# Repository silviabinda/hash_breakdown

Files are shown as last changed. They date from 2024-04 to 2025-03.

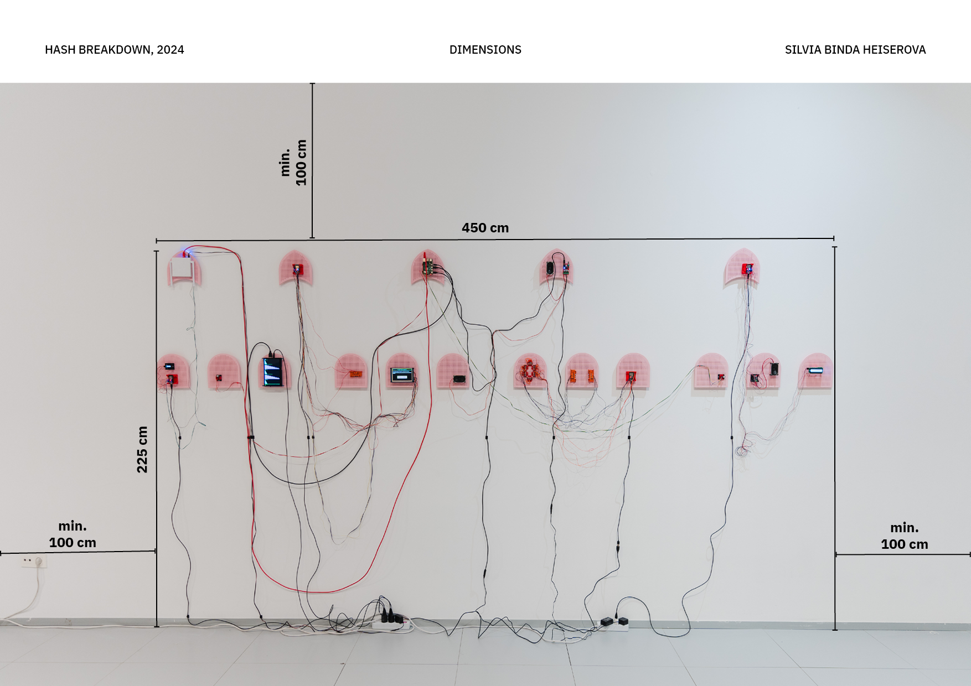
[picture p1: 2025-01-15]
schematics/dimensions.png

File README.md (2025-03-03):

# Hash Breakdown, 2024
SILVIA_BINDA_ETOPIA_JULIAN-FALLAS-28 copy
>Photo by: Julian Fallas

## About
The artwork “Hash Breakdown" is an autonomous system constituted by an electronic and digital ensamble of microcomputers, modules, 3D prints, sensors and codes with real-time functionality. This critical interface parses sentences related to the keywords “feminism is” from the world wide web and then starts a slowed-down explanatory process of converting the parsed sentence into a hash, using the SHA-256 algorithm. What normally takes less than a millisecond, is here extended into a 4-minute explanatory cycle, represented visually within a structure imitating a simplified logic gates diagram of the very same SHA-256 hashing function.

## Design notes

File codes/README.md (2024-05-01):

# ESP32 general information:

The esp32_1 to esp32_4 codes are run on an ESP32 WROOM 30PIN model with following PinOuts:

ESP32_Pinout

> Image source and more info: https://circuits4you.com/2018/12/31/esp32-devkit-esp32-wroom-gpio-pinout/

# Communication with Raspberry Pi4 model B
Each of the ESP32 receives UDP messages from the Raspberry Pi4 model B via Wifi using an offline router with IP adresses reserved for each of the ESP32.

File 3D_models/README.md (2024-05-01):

# Info on 3D models

In the folder "3D_models", you can find .stl files of all the 3D printed parts that are included in the Hash Breakdown artwork.

First, print the base modules from the folder "base". Altoghether, in the final set up, there are 17 basic modules, 5 of which represent the OR logic gate and 12 representing the AND logic gate.

In the "holders" folder, you will find different types of holders for components such as ESP32, amplifier, oled display.

Finally, in the "wall_mount" folder there is the piece that serves to mount the module on the wall, print 1 piece for each module, in this case that would be 17 piecies.  

# Details on 3D printed parts:

- 3D printer used: Sovol SV07 
- Rose filament: eSUN ePLA-Matte Peach Pink
- Red filament: eSUN PLA+ red
- Black filament: generic PLA matte

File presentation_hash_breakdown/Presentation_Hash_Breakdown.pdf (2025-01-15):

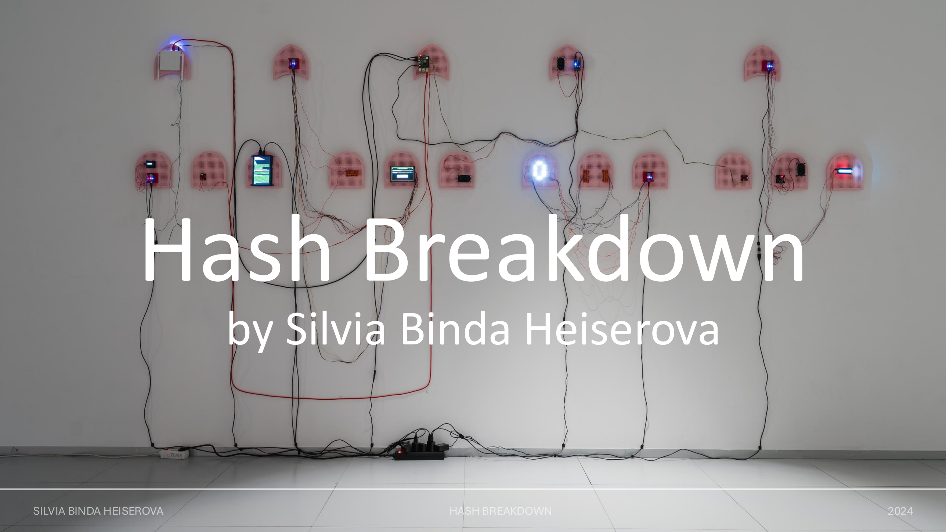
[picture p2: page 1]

# Hash Breakdown

### by Silvia Binda Heiserova

1

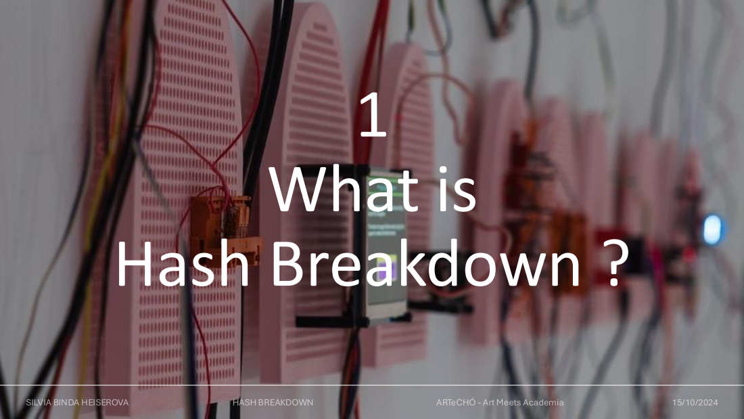
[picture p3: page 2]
What is Hash Breakdown ?

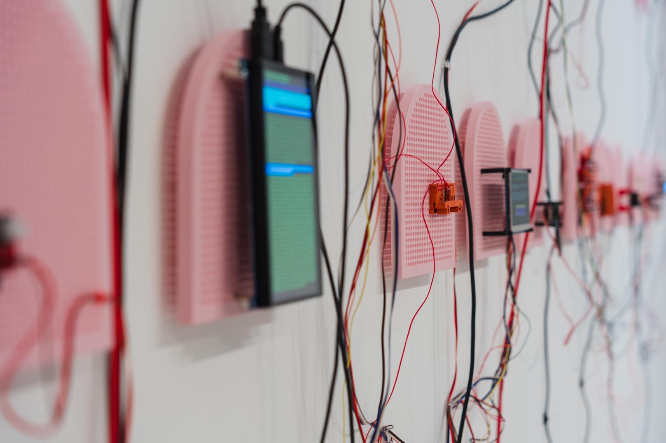
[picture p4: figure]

# Critical Interface

demystifying the
SHA-256 hashing
algorithm

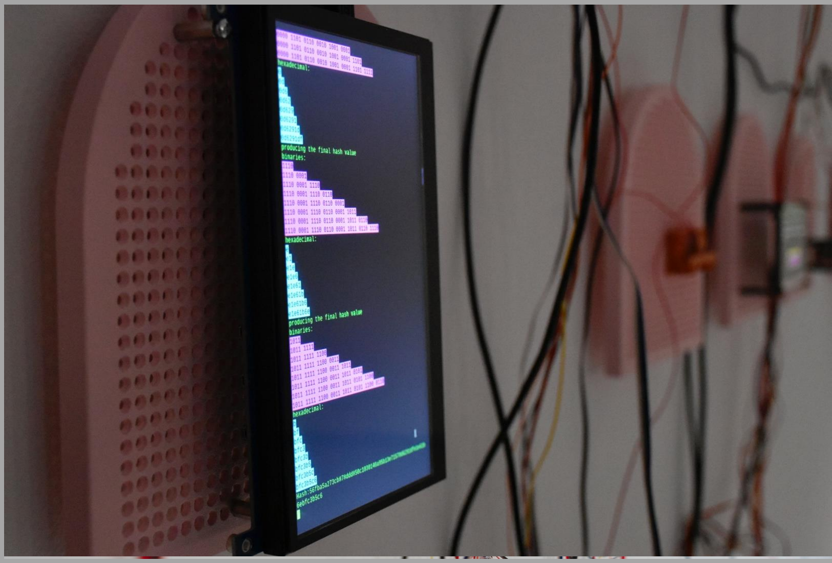
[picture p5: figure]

# Critique

towards mystifying,
elitist, masculine
narratives around
blockchain

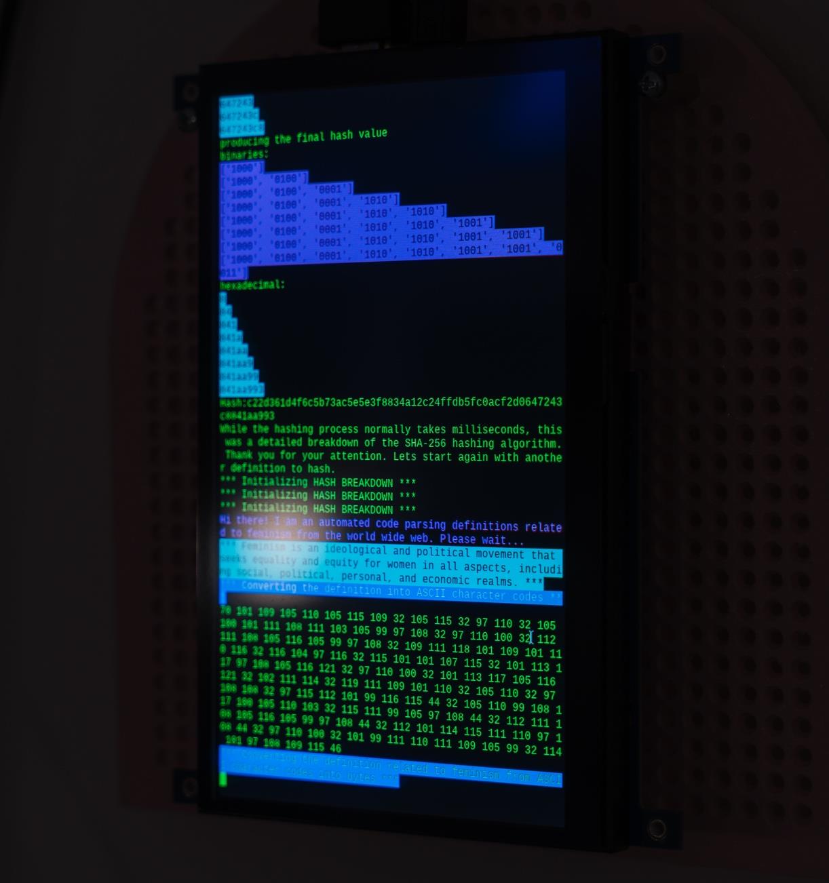
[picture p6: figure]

# Explanatory Process

slowed-down version
of the data conversion into a hash

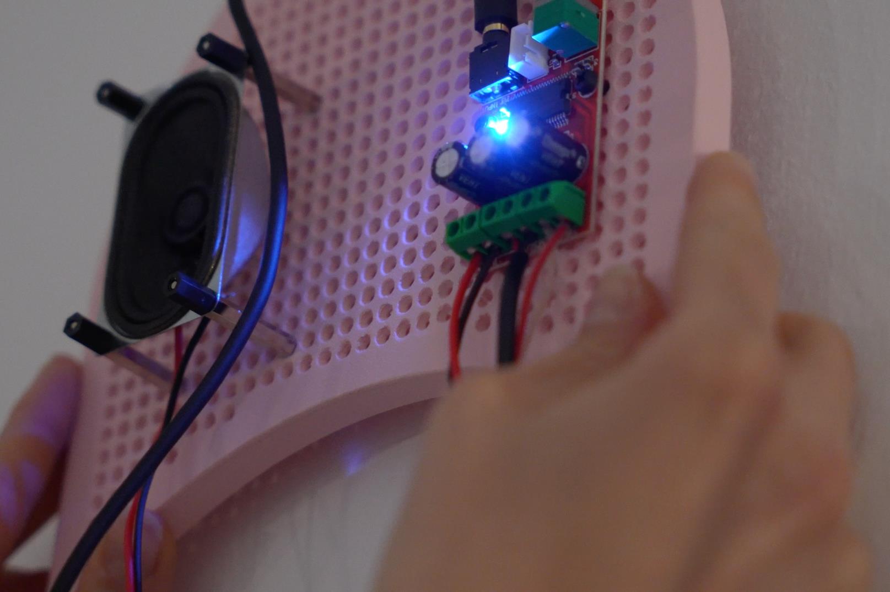
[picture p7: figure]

Material,
Visual,

# Sonic

representation of
SHA-256

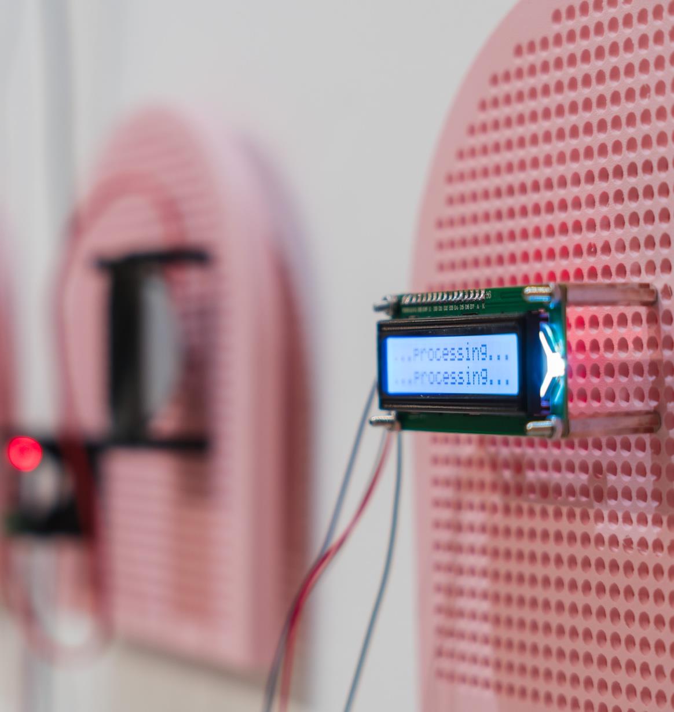
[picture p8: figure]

# Autonomous System

making SHA-256
more readable, tangible,
comprehensible

# Open Hardware

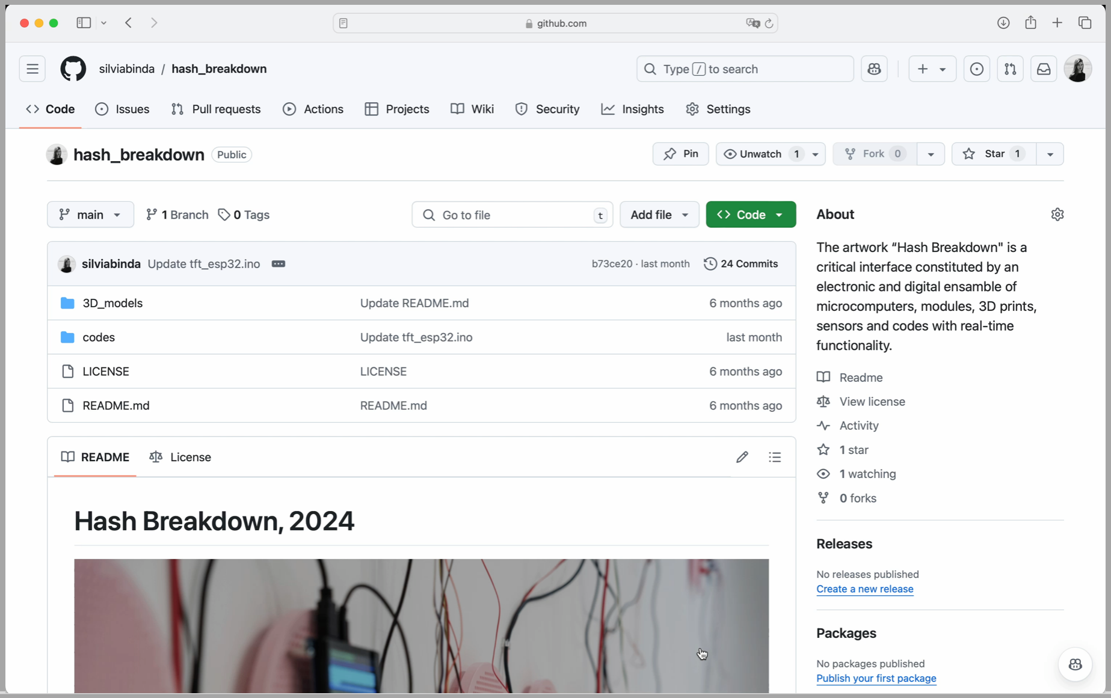
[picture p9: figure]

2

# Video Preview

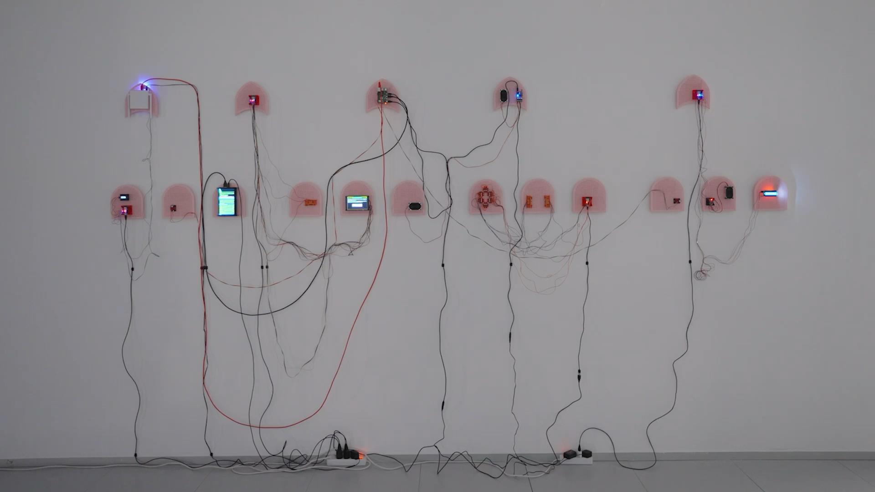
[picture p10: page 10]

3

# Technical Aspects

# 3D Prints

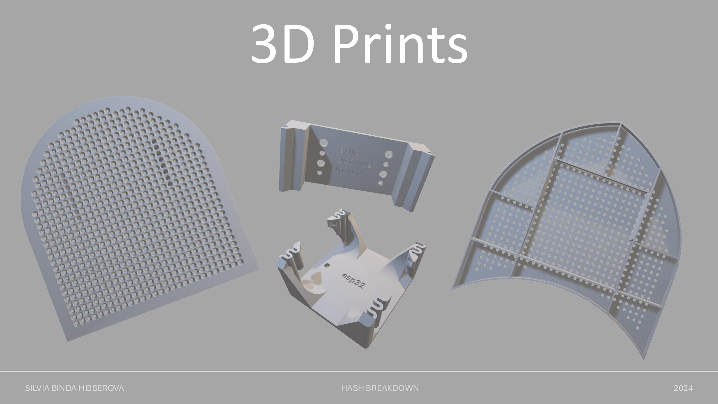
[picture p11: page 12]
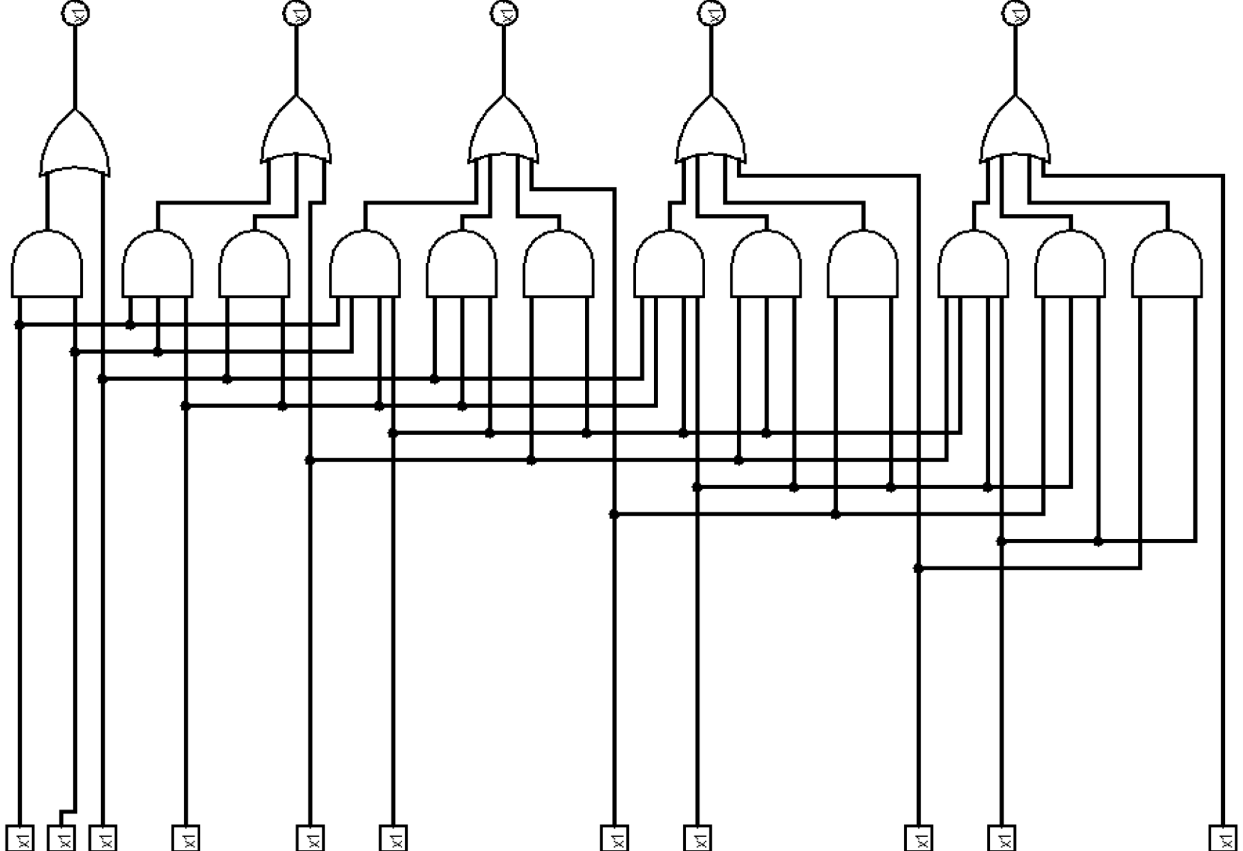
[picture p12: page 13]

# Connection schematic

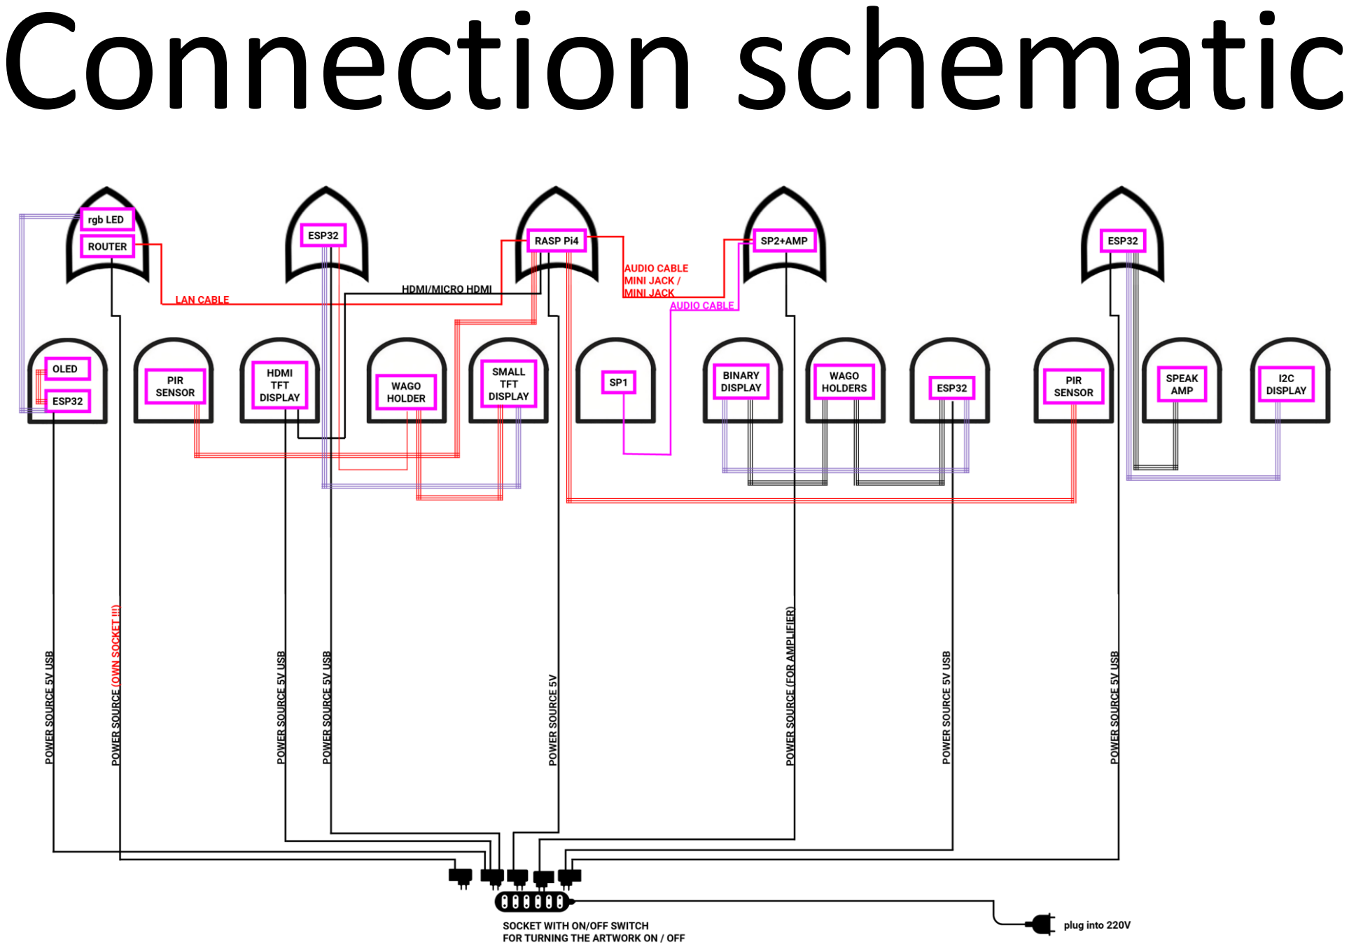
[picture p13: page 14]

# Micro/Minicomputers

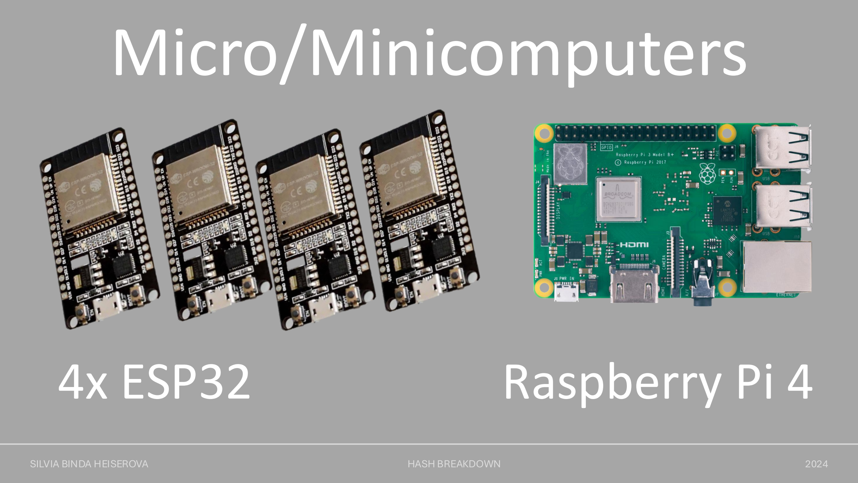
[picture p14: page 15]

4x ESP32 | Raspberry Pi 4

# Coding

Main code (RasPi)

- written in Python
- Python implementation of SHA-256
- Python script for parsing data to be hashed
- Backup database
- TTS python library (real time synthesis)

# Coding

ESP32 codes

- Python or C++ based
- Control of specific modules (amplifier, display, LEDs…)
- Receiving Data from RasPi (UDP) via
offline router

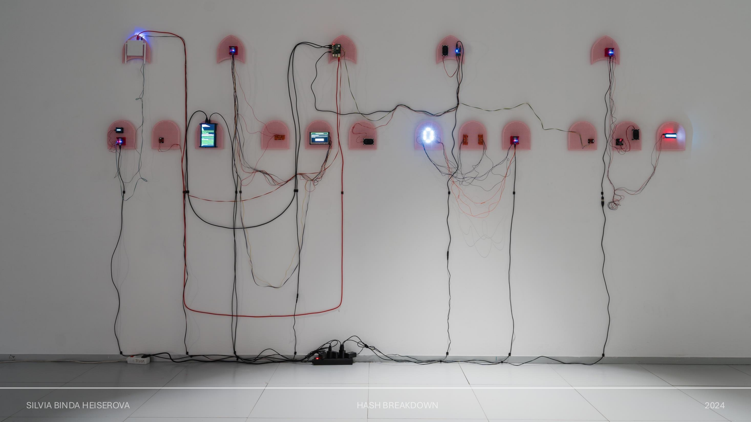
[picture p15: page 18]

# 4 Conclusion

➔Blockchain as a space for critical reflection from a feminist perspective.
➔Blockchain as a technology to be demystified and democratized.
➔Reclaiming technology through transparency and Open Source principles

# Thank You

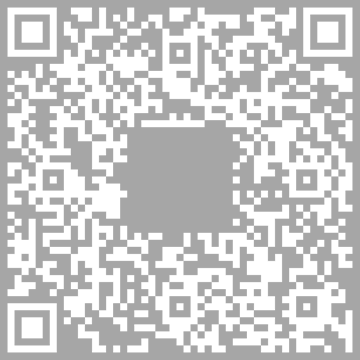
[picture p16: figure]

silviaheiserova@gmail.com

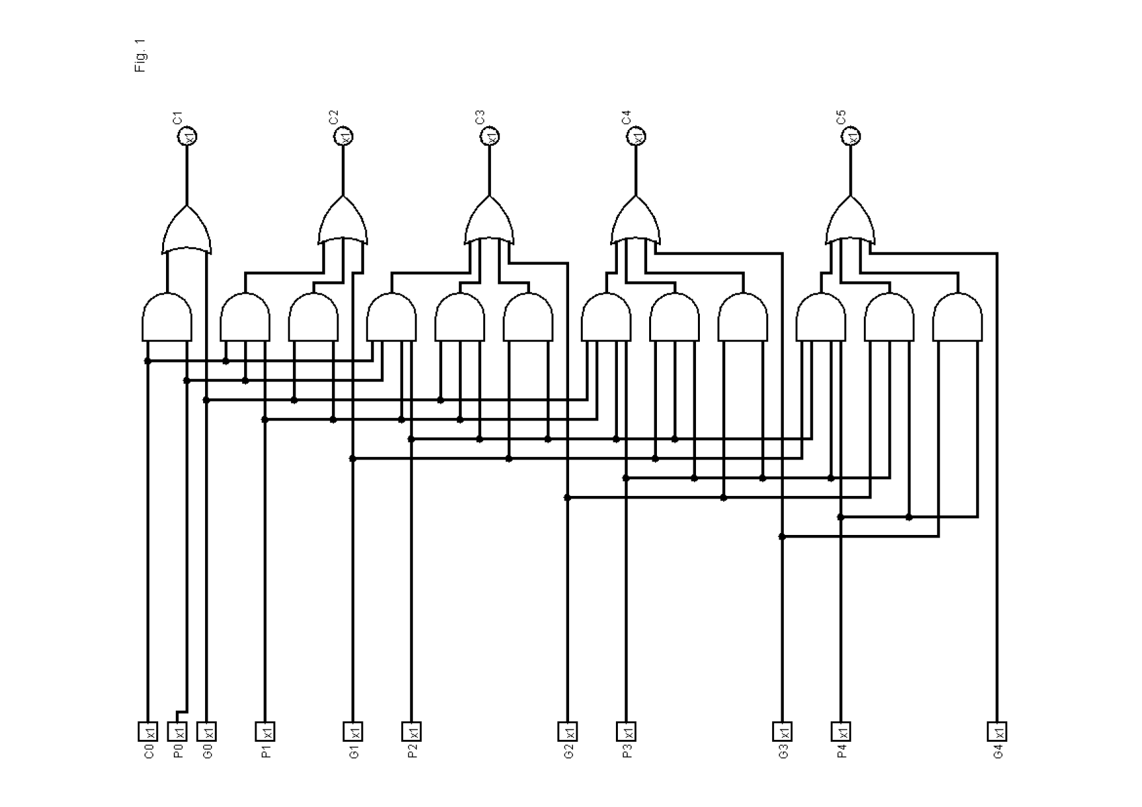
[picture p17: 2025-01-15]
schematics/logic_diagram.png

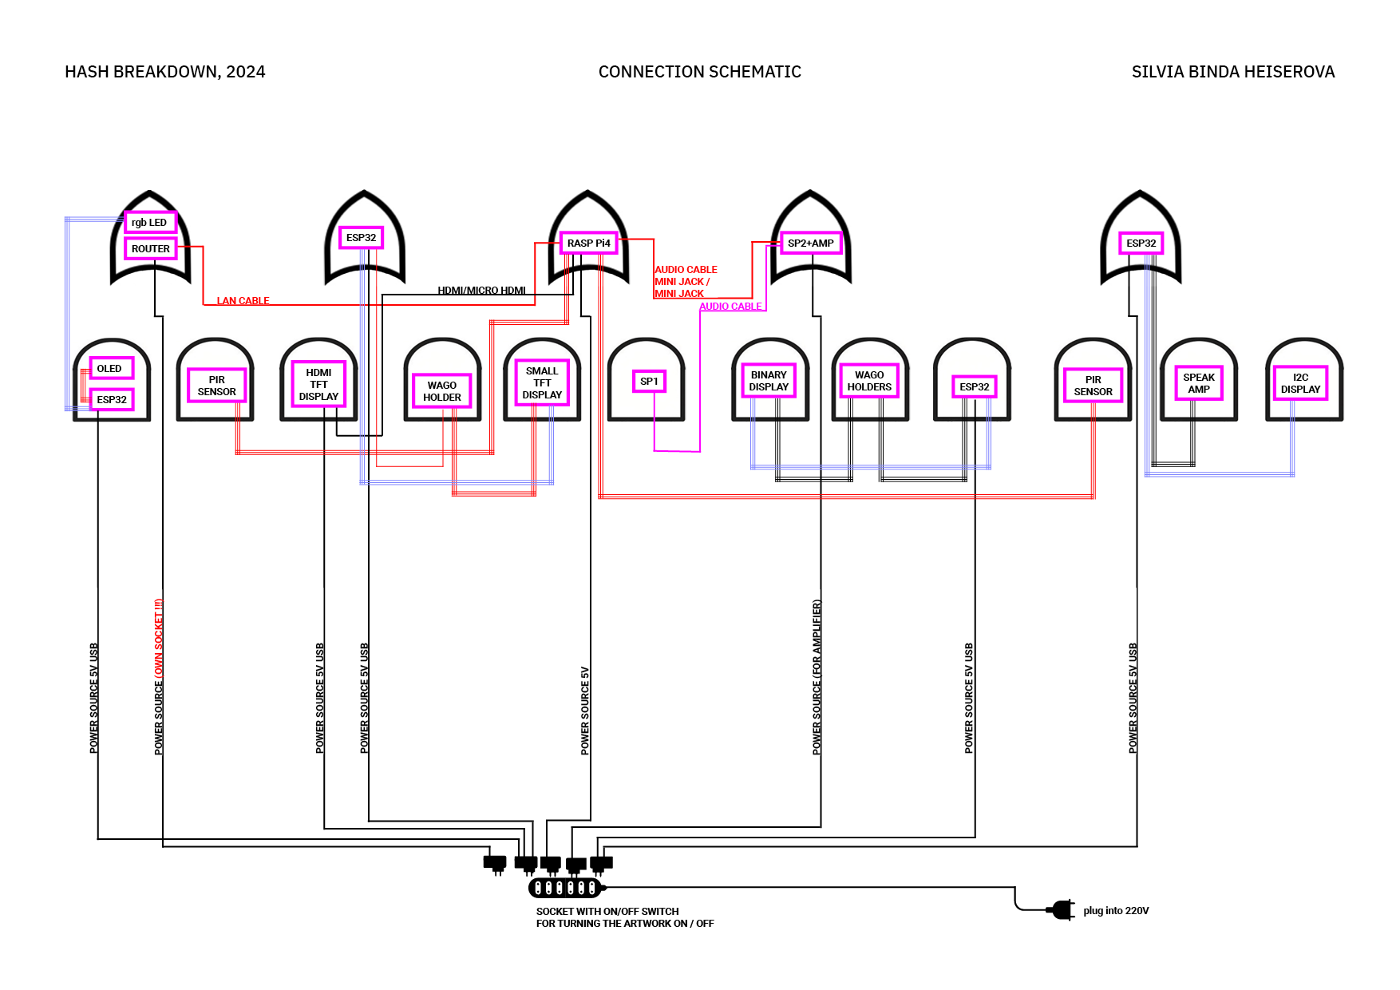
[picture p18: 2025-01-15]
schematics/connection_schematics.png

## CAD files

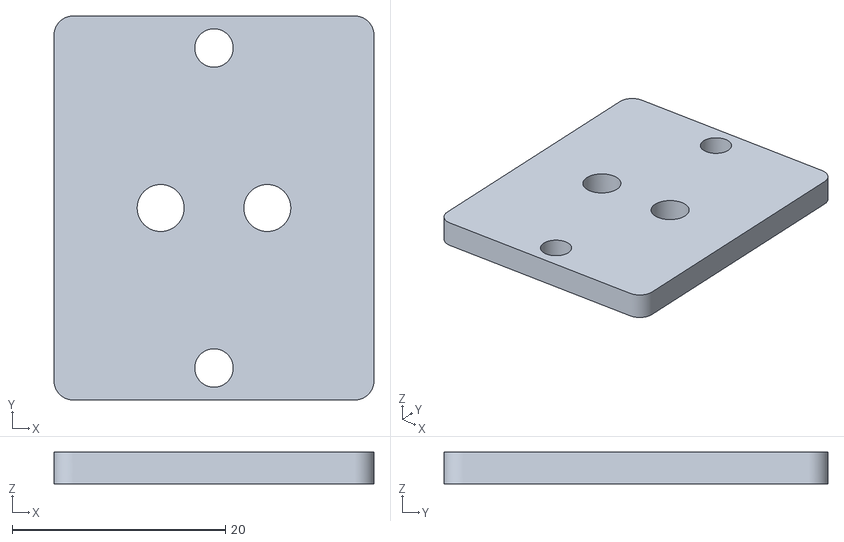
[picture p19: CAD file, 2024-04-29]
3D_models/holders/tiny1.stl
30.0 x 36.0 x 3.00

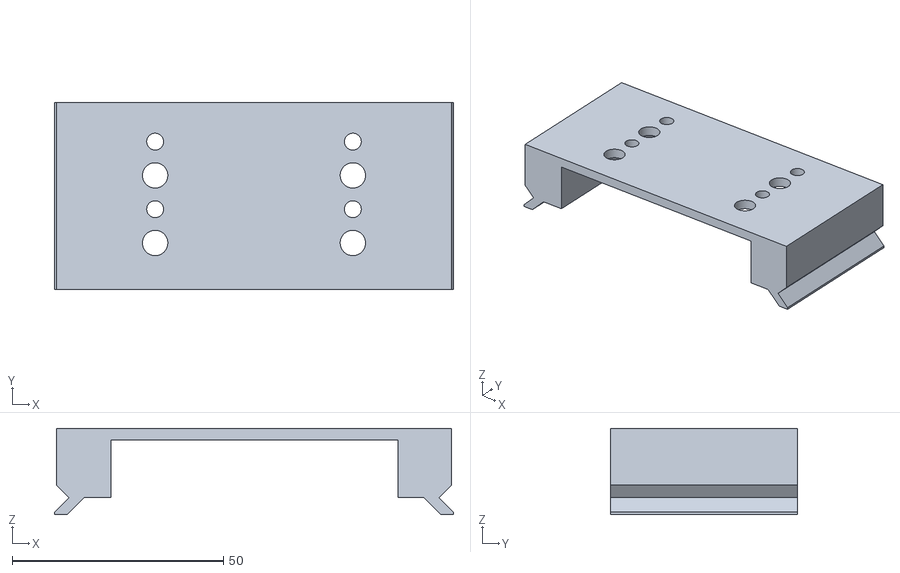
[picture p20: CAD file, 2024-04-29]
3D_models/wall_mount/WALLmount_extra_distance_text.stl
94.5 x 44.3 x 20.4

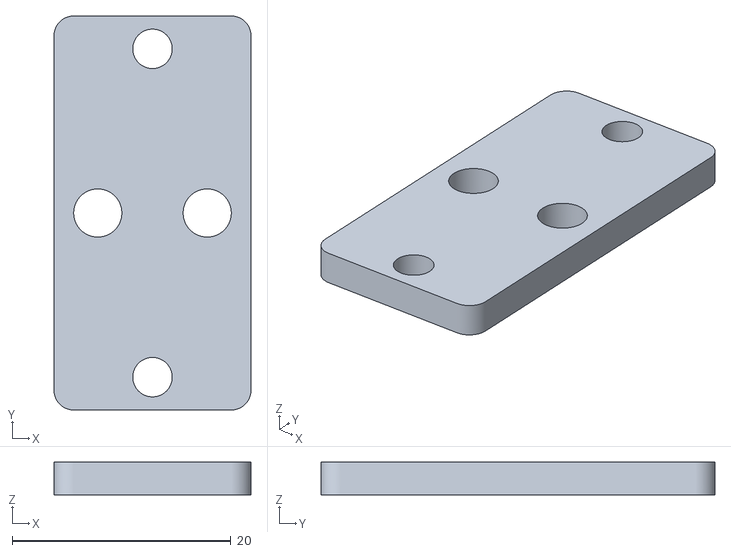
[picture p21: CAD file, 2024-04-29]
3D_models/holders/tiny2.stl
18.0 x 36.0 x 3.00

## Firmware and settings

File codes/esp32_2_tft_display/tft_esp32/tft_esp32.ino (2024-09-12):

/* 

SPDX-FileCopyrightText: © 2024 Silvia Binda Heiserova silviaheiserova@gmail.com

SPDX-License-Identifier: MIT

::::::::::::::::::::::::::::::::::::::::::::::::::::::::::::::::::::::::::::::::::::
::::::::::::: Hash Breakdown by Silvia Binda Heiserova, 2024 :::::::::::::::::::::::
::::::::::::::::::::::::::::::::::::::::::::::::::::::::::::::::::::::::::::::::::::
:::::::::::: CODE EXECUTED FROM ESP32 (TFT Display "small") :::::::::::::::::::::::::::
::::::::::::::::::::::::::::::::::::::::::::::::::::::::::::::::::::::::::::::::::::

ESP32 details: 
Device Name: esp32-9FFE8C
MAC Address: 24-DC-C3-9F-FE-8C
Reserved IP Address: 192.168.0.103

TFT display details:
Resolution: 800 x 480 pixel
Driver: SSD1963
bought from: https://techfun.sk/produkt/nedotykovy-5-displej-800x480/

******************************************************************************************************************************
This code is executed on ESP32, which is physically connected to the TFT 800x480px display.
Connection to GPIOs:
CS -> GPIO33
RS/DC -> GPIO15
RST -> GPIO32
WR -> GPIO4
RD -> GPIO2
LED_A -> 3.3V
3.3V -> 3V3
GND -> GND
db0 -> GPIO12
db1 -> GPIO13
db2 -> GPIO26
db3 -> GPIO18
db4 -> GPIO17
db5 -> GPIO16
db6 -> GPIO27
db7 -> GPIO14

!!! NEVER USE GPIO25 WHEN WORKING WITH WIFI ON ESP32 !!!

The code does 2 basic tasks: 

1) Receiving messages (variable called "message") from PC (Raspberry Pi 4) via UDP communication. 
      //for this UDP communication we use an offline router, which is connected via Wifi to this ESP32 and via LAN cable to PC
      //we have previously set a stable IP address on the router for PC and for this ESP32
              
2) Displaying the received messages on the TFT display
      
******************************************************************************************************************************
*/

//libraries for controlling the TFT display
#include "SPI.h"
#include "TFT_eSPI.h"

//include this font
#include "NotoSansMonoSCB20.h"
#include "Final_Frontier_28.h"
#include "Latin_Hiragana_24.h"
#include "NotoSansBold36.h"

//library for wifi connection to our offline router for udp communication:
#include <WiFi.h>

//library for udp communication:
#include <WiFiUdp.h>

//#include "Free_Fonts.h" // Include the free fonts library Free_Fonts.h if needed (copy it to the same folder as this code)

// The font names are arrays references, thus must NOT be in quotes ""
#define AA_FONT_HEADER NotoSansMonoSCB20
#define AA_FONT_TEXT Final_Frontier_28
#define AA_FONT_LATIN Latin_Hiragana_24
#define AA_FONT_RECT NotoSansBold36

int rectWidth = 400; // Width of the rectangle
int rectHeight = 200; // Height of the rectangle

//int rectX = (tft.width() - rectWidth) / 2; // X-coordinate of the top-left corner of the rectangle
//int rectY = (tft.height()) / 2 + 40; // Y-coordinate of the top-left corner of the rectangle


// Use hardware SPI
TFT_eSPI tft = TFT_eSPI();
TFT_eSprite spr = TFT_eSprite(&tft); // Sprite class needs to be invoked

unsigned long drawTime = 0;

//create UDP instance:
WiFiUDP udp;

//set the port number (will be used for receiving messages from PC):
const int udpPort = 8345;

//function for connecting esp32 to Wifi router:
void initWiFi() 
{
  WiFi.mode(WIFI_STA);
  WiFi.begin("SSID", "password"); //ssid and password of offline router
  Serial.println("connecting to wifi ...");
  while (WiFi.status() != WL_CONNECTED) 
  {
    Serial.print('.');
    delay(1000);
  }
  //prints the ip address of esp32 if connected:
  Serial.println(WiFi.localIP());
}


void setup(void) {
  // initializing Wifi connection to offline router and udp messages receiving
  Serial.begin(9600);
  initWiFi();
  udp.begin(udpPort);
  Serial.print("start"); 
  Serial.print(tft.height());
  Serial.print(tft.width());

  // initializing and initial setting of the tft dislpay:
  tft.begin();
  tft.setRotation(1); //horizontal

  spr.setColorDepth(16); // 16-bit colour needed to show antialiased fonts
}

void loop() {

  //tft.fillScreen(TFT_BLACK);

  int xpos = tft.width();
  int ypos = tft.height();

  char message[500]; //set a limit of the characters of the message
  memset(message, 0, 500);
  //processing incoming packet, must be called before reading the buffer:
  udp.parsePacket();
  //receive response from server:
  if(udp.read(message, 500) > 0)
  //!! problem ze mi vzdy posuva riadok dolu
  //skus set cursor radu od gpt
  {
  //tft.loadFont(AA_FONT_HEADER);
    tft.loadFont(AA_FONT_LATIN);
    tft.fillScreen(TFT_BLACK);
    tft.fillRect(0, 0, 800, 60, TFT_GREEN); //(x, y, width, height, color);
    tft.fillRect(5, 5, 790, 50, TFT_BLACK);
    //tft.fillRect(0, 61, 800, 180, TFT_BLACK);
    tft.setCursor(8, 0); //Set fixed values for the cursor so the text appears on the same place always
    //tft.setTextFont(4);
    //tft.setTextFont(&NotoSansBold36);
    tft.setTextWrap(true); // Wrap on width
    tft.setTextColor(TFT_YELLOW); //or CYAN
    // //tft.drawString("1234567", 240, 160, 7);
    tft.println();
    //tft.print("  *** This is the definition of feminism I found in the world wide web: ***");
    //tft.print("  THIS IS THE DEFINITION OF FEMINISM I FOUND IN THE WORDL WIDE WEB:");
    tft.print("                            *** H A S H  B R E A K D O W N ***");
    tft.println();
    tft.println();
    tft.print("    ");
    tft.setTextColor(TFT_WHITE);
    tft.loadFont(AA_FONT_TEXT);
    tft.print(message);

    delay(10000);
    blinkText();

  }

  // ??? Dalsiu spravu (final hash) ako vytlacit ? //if(udp.read(message, 500) == 64))
  // }

}

void blinkText() {
  tft.loadFont(AA_FONT_RECT);
  tft.setTextColor(TFT_BLACK);
  tft.fillRect(190, 300, 410, 100, TFT_CYAN);
  tft.fillRect(210, 325, 380, 70, TFT_GREEN);
  bool magentaColor = true; // Initial color state
  if (magentaColor) {
    tft.fillRect(210, 325, 380, 70, TFT_MAGENTA);
  } else {
    tft.fillRect(205, 305, 390, 90, TFT_GREEN);
  }
  magentaColor = !magentaColor; // Toggle the color state
  tft.drawString("hashing in progress", 210, 330, 4); // Font 4 for fast drawing with background
  
}

#ifndef LOAD_GLCD
//ERROR_Please_enable_LOAD_GLCD_in_User_Setup
#endif

#ifndef LOAD_FONT2
//ERROR_Please_enable_LOAD_FONT2_in_User_Setup!
#endif

#ifndef LOAD_FONT4
//ERROR_Please_enable_LOAD_FONT4_in_User_Setup!
#endif

#ifndef LOAD_FONT6
//ERROR_Please_enable_LOAD_FONT6_in_User_Setup!
#endif

#ifndef LOAD_FONT7
//ERROR_Please_enable_LOAD_FONT7_in_User_Setup!
#endif

#ifndef LOAD_FONT8
ERROR_Please_enable_LOAD_FONT8_in_User_Setup!
#endif

#ifndef LOAD_GFXFF
ERROR_Please_enable_LOAD_GFXFF_in_User_Setup!
#endif

/*
  This code is using parts of the example that draws fonts (as used by the Adafruit_GFX library) onto the
  screen. These fonts are called the GFX Free Fonts (GFXFF) in this library.

  Other True Type fonts could be converted using the utility within the
  "fontconvert" folder inside the library. This converted has also been
  copied from the Adafruit_GFX library.

  Since these fonts are a recent addition Adafruit do not have a tutorial
  available yet on how to use the utility.   Linux users will no doubt
  figure it out!  In the meantime there are 48 font files to use in sizes
  from 9 point to 24 point, and in normal, bold, and italic or oblique
  styles.

  This example sketch uses both the print class and drawString() functions
  to plot text to the screen.

  Make sure LOAD_GFXFF is defined in the User_Setup.h file within the
  TFT_eSPI library folder.

  --------------------------- NOTE ----------------------------------------
  The free font encoding format does not lend itself easily to plotting
  the background without flicker. For values that changes on screen it is
  better to use Fonts 1- 8 which are encoded specifically for rapid
  drawing with background.
  -------------------------------------------------------------------------
  
  >>>>>>>>>>>>>>>>>>>>>>>>>>> WARNING <<<<<<<<<<<<<<<<<<<<<<<<<<<<<<<<<<<<<

  As supplied with the default settings the sketch has 11 fonts loaded,
  i.e. GLCD (Font 1), Font 2, Font 4, Font 6, Font 7, Font 8 and five Free Fonts,
  even though they are not all used in the sketch.
  
  Disable fonts you do not need in User_Setup.h in the library folder.

  #########################################################################
  ###### DON'T FORGET TO UPDATE THE User_Setup.h FILE IN THE LIBRARY ######
  #########################################################################
*/

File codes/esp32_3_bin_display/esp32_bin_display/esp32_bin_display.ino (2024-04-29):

/* 

SPDX-FileCopyrightText: © 2024 Silvia Binda Heiserova silviaheiserova@gmail.com

SPDX-License-Identifier: MIT

::::::::::::::::::::::::::::::::::::::::::::::::::::::::::::::::::::::::::::::::::::
::::::::::::: Hash Breakdown by Silvia Binda Heiserova, 2024 :::::::::::::::::::::::
::::::::::::::::::::::::::::::::::::::::::::::::::::::::::::::::::::::::::::::::::::
:::::::::::: CODE EXECUTED FROM ESP32 (Binary Display) :::::::::::::::::::::::::::
::::::::::::::::::::::::::::::::::::::::::::::::::::::::::::::::::::::::::::::::::::

ESP32 details: 
Device Name: esp32-A045E8
MAC Address: 24-DC-C3-A0-45-E8
Reserved IP Address: 192.168.0.101
******************************************************************************************************************************
This code is executed on ESP32, which is physically connected to DIY Binary Display.
The code does 2 basic tasks: 

1) Receiving a message (variable called "message") from PC (Raspberry Pi 4) via UDP communication. 
      /for this UDP communication we use an offline router, which is connected via Wifi to this ESP32 and via LAN cable to PC
      /we have previously set a stable IP address on the router for PC and for this ESP32
              
2) Displaying the received messages on a DIY Binary Display:
      /we will display the received messages, which in our case is a 0 or a 1
      
******************************************************************************************************************************

________________________________________________________________________________________________________________

The code is run on an ESP32 microcontroller which is connected to the 18 led diodes.
The LED diodes are designed and coded to form a 6 segment numeric display displaying the number 0 or 1.
In each segment, there are 3 LED diodes connected to one pin of the ESP32 WROOM as follows:  

      GPIO23  
        _
GPIO27 | | GPIO22
GPIO26 |_| GPIO19
      GPIO32

NOTE: GPIO25 is interfering with Wifi function of the ESP32 !!!! (Do not use it)

LED diode cathodes (-) are connected to the GND pin on ESP32 via the breadboard with 25 pins.

There is a color pattern applied to the wiring:
Connections from LED diode anodes (+) => red orange wires 
Connections from LED diode cathodes (-) and connection to GND pin of the ESP32 => black color wires
Connection from breadboards size M to respective GPIOs of the ESP32 => violet and orange color wires
________________________________________________________________________________________________________________
*/

//library for wifi connection to our offline router for udp communication:
#include <WiFi.h>

//library for udp communication:
#include <WiFiUdp.h>

//create UDP instance:
WiFiUDP udp;
//set the port number (will be used for receiving messages from PC):
const int udpPort = 8345;

//function for connecting esp32 to Wifi router:
void initWiFi() 
{
  WiFi.mode(WIFI_STA);
  WiFi.begin("SSID", "password"); //ssid and password of offline router
  Serial.println("connecting to wifi ...");
  while (WiFi.status() != WL_CONNECTED) 
  {
    Serial.print('.');
    delay(1000);
  }
  //prints the ip address of esp32 if connected:
  Serial.println(WiFi.localIP());
}

//Define the pins:

int pin_led1 = 23;
int pin_led2 = 22;
int pin_led3 = 19;
int pin_led5 = 27;
int pin_led6 = 26;
int pin_led7 = 32;

//functions for writing numbers on the binary display:
void num_off ()
{
  digitalWrite(pin_led1, LOW);
  digitalWrite(pin_led2, LOW);
  digitalWrite(pin_led3, LOW);
  digitalWrite(pin_led5, LOW);
  digitalWrite(pin_led6, LOW);
  digitalWrite(pin_led7, LOW);
}

void num_zero ()
{
  digitalWrite(pin_led1, HIGH);
  digitalWrite(pin_led2, HIGH);
  digitalWrite(pin_led3, HIGH);
  digitalWrite(pin_led5, HIGH);
  digitalWrite(pin_led6, HIGH);
  digitalWrite(pin_led7, HIGH);
}

void num_one ()
{
  digitalWrite(pin_led1, LOW);
  digitalWrite(pin_led2, HIGH);
  digitalWrite(pin_led3, HIGH);
  digitalWrite(pin_led5, LOW);
  digitalWrite(pin_led6, LOW);
  digitalWrite(pin_led7, LOW);
}


void setup() 
{
  int BUILT_IN_LED = 2; //GPIO of the built in led on ESP32
  //to turn off the built in LED on the ESP32:
  pinMode(BUILT_IN_LED, OUTPUT);
  digitalWrite(BUILT_IN_LED, HIGH);

  pinMode(pin_led1, OUTPUT);
  pinMode(pin_led2, OUTPUT);
  pinMode(pin_led3, OUTPUT);
  pinMode(pin_led5, OUTPUT);
  pinMode(pin_led6, OUTPUT);
  pinMode(pin_led7, OUTPUT);
  Serial.begin(9600);
  initWiFi();
  udp.begin(udpPort);
  Serial.print("start"); 
  // empty display:
  num_off();
}

void loop() 
{
  char message[60]; //set some initial text for the message
  memset(message, 0, 60);
  //processing incoming packet, must be called before reading the buffer:
  udp.parsePacket();
  //receive response from server:
  if(udp.read(message, 60) > 0)
  {
    Serial.print("Sent from main code: ");
    Serial.println((char *)message);
    int message_length = 60;
    if (sizeof(message)<message_length)
    {
      message_length = sizeof(message);
    }
    
    for (int i=0; i<message_length; i++)
    {
      char bit = message[i];

      if (bit == '0') 
      {
        num_zero();
        delay(300);
        num_off();
        delay(200);
      }
      if (bit == '1') 
      {
        num_one();
        delay(200);
        num_off();
        delay(200);
      }
      //else {
      //  num_one();
      //}
 
    }
    //delay(1000);
  }
}

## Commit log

2024-04-30 Delete codes/esp32_1_oled_display/text_on_i2c_lcd directory
    was a code for testing purposes only
2024-09-12 Update tft_esp32.ino
    correction in comments
    [tft_esp32.ino]
2025-01-14 Codes to be run from Raspberry Pi
